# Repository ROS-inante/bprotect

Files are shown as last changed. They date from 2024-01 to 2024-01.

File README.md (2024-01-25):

# BProtect

This repository contains the design files and firmware for the BProtect battery management board.

## Overview
The battery management system consists of a LTC4281 Hot-Swap controller handling the power path control as well as a Espressif ESP32 running the interfacing firmware. 

The design was created in KiCad and can be found in the [board](/board) folder.
Some notes about design considerations, component selection and sizing are contained in the schematic.

The ESP32 runs the awesome [Tasmota](https://tasmota.github.io/docs/) firmware and has a custom driver for the LTC4281 written in [Berry](https://berry-lang.github.io/). It can be found in the [app](/app) folder.

## Usage
Assemble the board as per schematics and flash Tasmota (version >=13).
Drop the Berry-script named [ltc4281.be](/app/ltc4281.be) from the [app](/app) folder into the filesystem and add it to the 'autoexec.be' as per the example.

## License
This project is licensed under the GPLv3.

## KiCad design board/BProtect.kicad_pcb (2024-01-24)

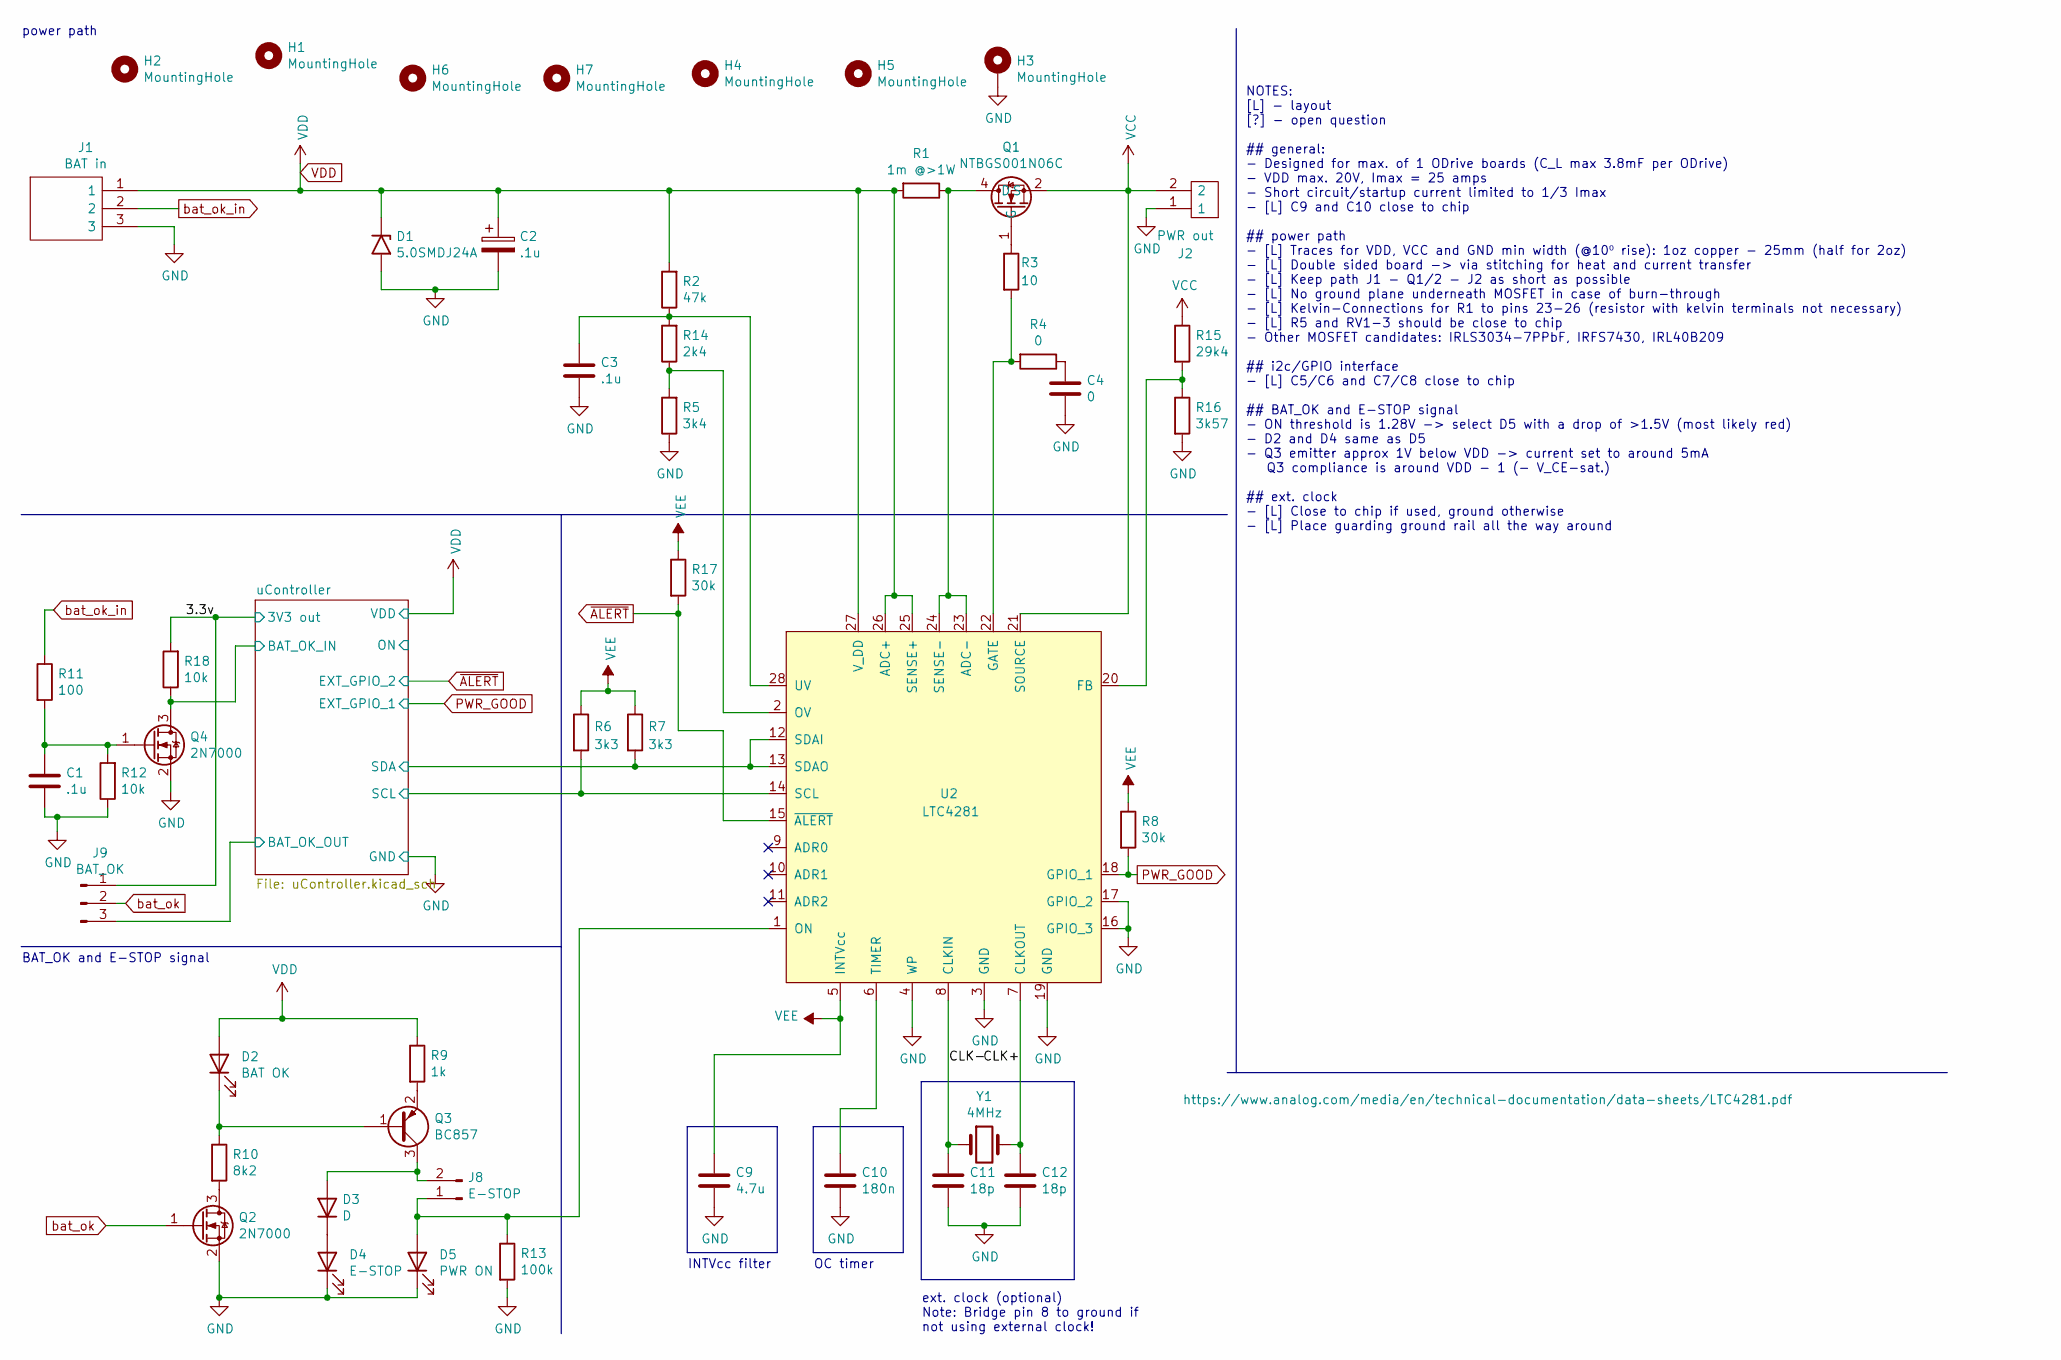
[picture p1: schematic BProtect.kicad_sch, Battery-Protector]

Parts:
C1, C3: .1u; C_1206_3216Metric_Pad1.33x1.80mm_HandSolder
C2: .1u; CP_Elec_4x5.4
C4: 0; C_1206_3216Metric_Pad1.33x1.80mm_HandSolder
C9: 4.7u; C_1206_3216Metric_Pad1.33x1.80mm_HandSolder
C10: 180n; C_1206_3216Metric_Pad1.33x1.80mm_HandSolder
C11, C12: 18p; C_0805_2012Metric_Pad1.18x1.45mm_HandSolder
D1: 5.0SMDJ24A; D_SMC_Handsoldering
D2: BAT OK; LED_1206_3216Metric_Pad1.42x1.75mm_HandSolder
D3: D; D_1206_3216Metric_Pad1.42x1.75mm_HandSolder
D4: E-STOP; LED_1206_3216Metric_Pad1.42x1.75mm_HandSolder
D5: PWR ON; LED_1206_3216Metric_Pad1.42x1.75mm_HandSolder
H1, H2, H3, H4, H5, H6, H7: MountingHole; MountingHole_3.2mm_M3_DIN965_Pad_TopBottom
J1: BAT in; 1017522
J2: PWR out; 1017521
J8: E-STOP; conn_SMD_1x03_P2.54mm_Horizontal
J9: BAT_OK; PinHeader_1x03_P2.54mm_Vertical_SMD_Pin1Left
Q1: NTBGS001N06C; TO-263-7_TabPin4
Q2, Q4: 2N7000; TSOT-23
Q3: BC857; TSOT-23
R1: 1m @>1W; R_Shunt_Vishay_WSR2_WSR3_KelvinConnection
R2: 47k; R_1206_3216Metric_Pad1.30x1.75mm_HandSolder
R3: 10; R_1206_3216Metric_Pad1.30x1.75mm_HandSolder
R4: 0; R_1206_3216Metric_Pad1.30x1.75mm_HandSolder
R5: 3k4; R_1206_3216Metric_Pad1.30x1.75mm_HandSolder
R6, R7: 3k3; R_1206_3216Metric_Pad1.30x1.75mm_HandSolder
R8, R17: 30k; R_1206_3216Metric_Pad1.30x1.75mm_HandSolder
R9: 1k; R_1206_3216Metric_Pad1.30x1.75mm_HandSolder
R10: 8k2; R_1206_3216Metric_Pad1.30x1.75mm_HandSolder
R11: 100; R_1206_3216Metric_Pad1.30x1.75mm_HandSolder
R12, R18: 10k; R_1206_3216Metric_Pad1.30x1.75mm_HandSolder
R13: 100k; R_1206_3216Metric_Pad1.30x1.75mm_HandSolder
R14: 2k4; R_1206_3216Metric_Pad1.30x1.75mm_HandSolder
R15: 29k4; R_1206_3216Metric_Pad1.30x1.75mm_HandSolder
R16: 3k57; R_1206_3216Metric_Pad1.30x1.75mm_HandSolder
U2: LTC4281; QFN-28-1EP_4x5mm_P0.5mm_EP2.65x3.65mm
Y1: 4MHz; Crystal_SMD_HC49-SD

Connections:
+3V3: J9.1, R18.2; also elsewhere on the board
/CLK+: C12.1, U2.7 (CLKOUT), Y1.2
/CLK-: C11.1, U2.8 (CLKIN), Y1.1
/uController/BAT_OK_IN: Q4.3 (D), R18.1; also elsewhere on the board
/uController/BAT_OK_OUT: J9.3; also elsewhere on the board
/uController/SCL: R6.2, U2.14 (SCL); also elsewhere on the board
/uController/SDA: R7.2, U2.12 (SDAI), U2.13 (SDAO); also elsewhere on the board
GND: C1.2, C2.2, C3.2, C4.2, C9.2, C10.2, C11.2, C12.2, D1.2 (A2), D4.1 (K), D5.1 (K), H3.1, J1.3, J2.1, Q2.2 (S), Q4.2 (S), R5.1, R12.1, R13.2, R16.2, U2.3 (GND), U2.4 (WP), U2.16 (GPIO_3), U2.17 (GPIO_2), U2.19 (GND), U2.29; also elsewhere on the board
unnamed: C1.1, Q4.1 (G), R11.2, R12.2
unnamed: C3.1, R2.1, R14.2, U2.28 (UV)
unnamed: C4.1, R4.1
unnamed: C10.1, U2.6 (TIMER)
unnamed: D2.1 (K), Q3.1 (B), R10.1
unnamed: D3.1 (K), D4.2 (A)
unnamed: D3.2 (A), J8.2, Q3.3 (C)
unnamed: D5.2 (A), J8.1, R13.1, U2.1 (ON)
unnamed: Q1.1 (G), R3.1
unnamed: Q2.3 (D), R10.2
unnamed: Q3.2 (E), R9.2
unnamed: R3.2, R4.2, U2.22 (GATE)
unnamed: R5.2, R14.1, U2.2 (OV)
unnamed: R15.2, R16.1, U2.20 (FB)
PWR_GOOD: R8.2, U2.18 (GPIO_1); also elsewhere on the board
VDD: C2.1, D1.1 (A1), D2.2 (A), J1.1, R1.2, R2.2, R9.1, U2.25 (SENSE+), U2.26 (ADC+), U2.27 (V_DD); also elsewhere on the board
VEE: C9.1, R6.1, R7.1, R8.1, R17.1, U2.5 (INTVcc)
bat_ok: J9.2, Q2.1 (G)
bat_ok_in: J1.2, R11.1
~ALERT: R17.2, U2.15 (~ALERT); also elsewhere on the board

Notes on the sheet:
INTVcc filter
NOTES: [L] - layout [?] - open question ## general: - Designed for max. of 1 ODrive boards (C_L max 3.8mF per ODrive) - VDD max. 20V, Imax = 25 amps - Short circuit/startup current limited to 1/3 Imax - [L] C9 and C10 close to chip ## power path - [L] Traces for VDD, VCC and GND min width (@10⁰ ris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
power path
BAT_OK and E-STOP signal
OC timer
ext. clock (optional) Note: Bridge pin 8 to ground if not using external clock!

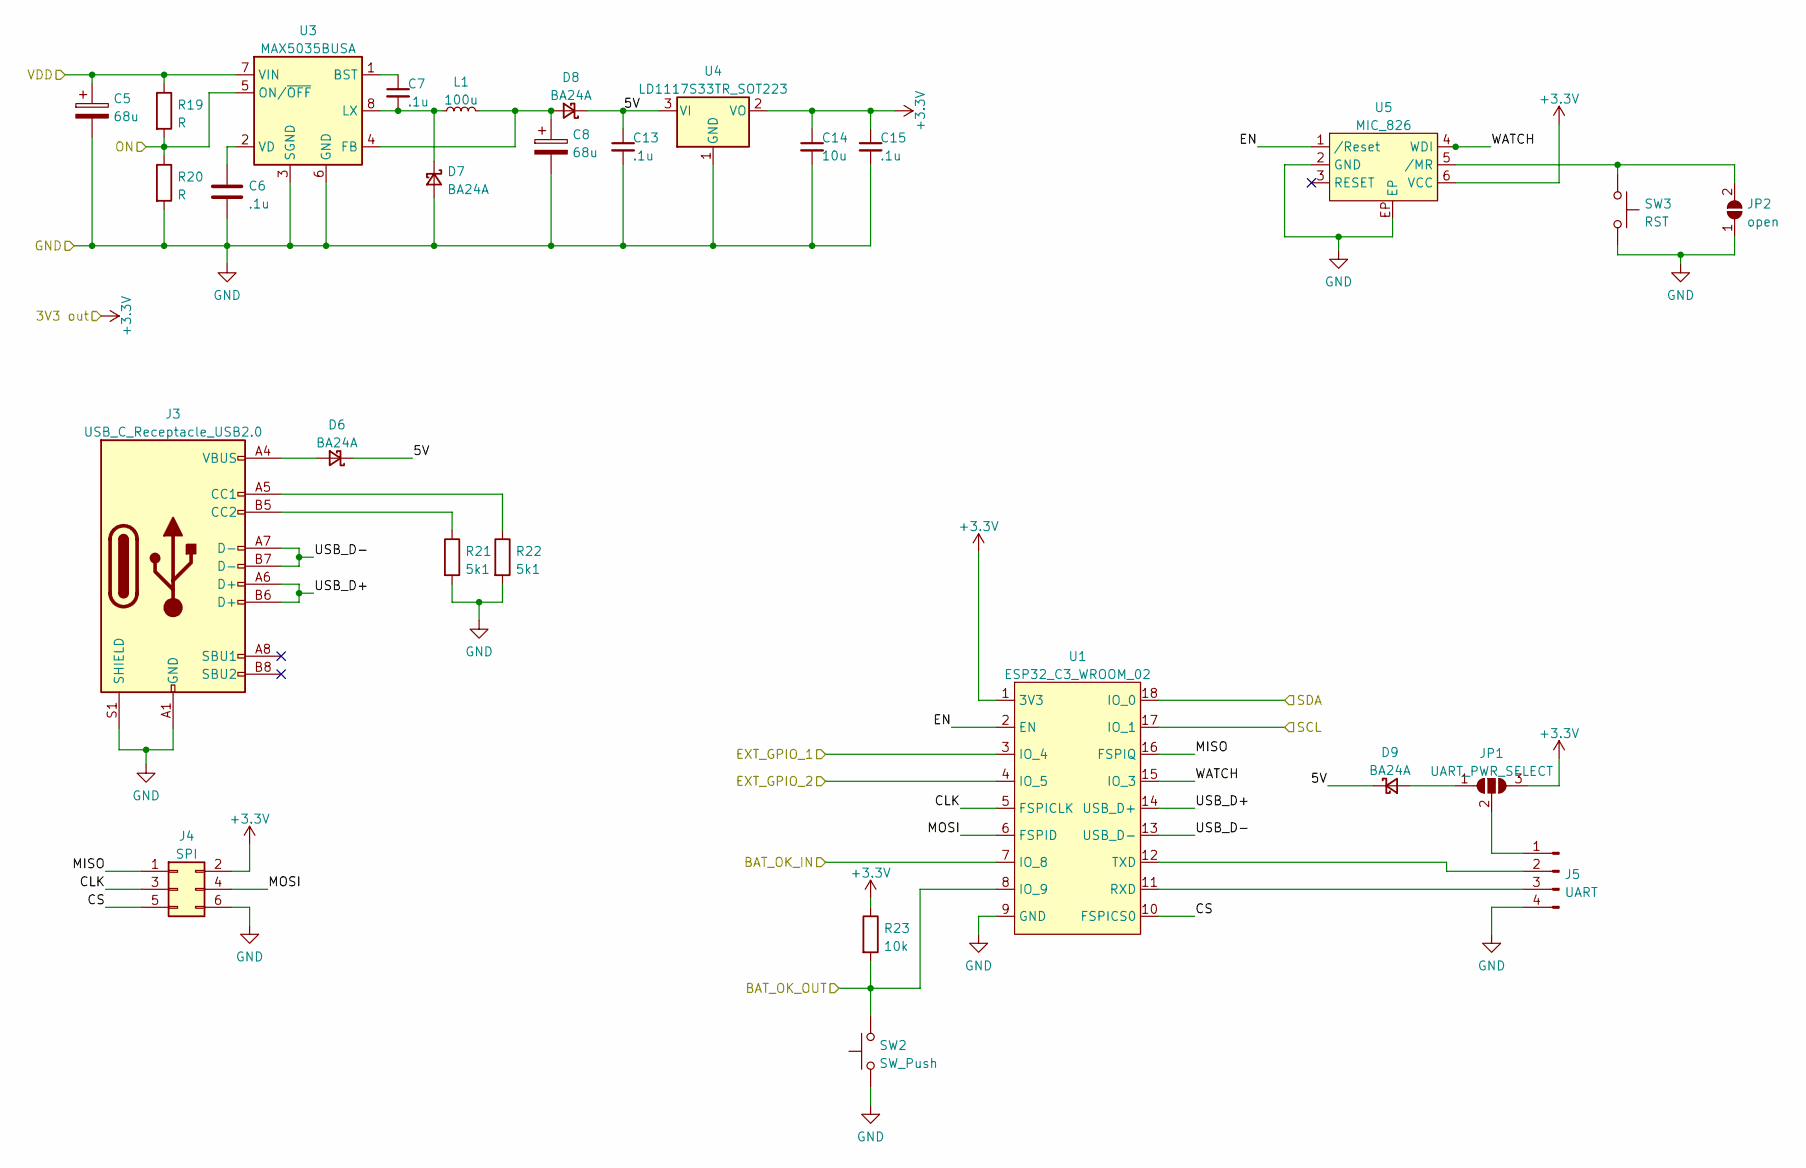
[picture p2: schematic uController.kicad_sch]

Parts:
C5, C8: 68u; CP_Elec_4x5.4
C6, C7, C13, C15: .1u; C_1206_3216Metric_Pad1.33x1.80mm_HandSolder
C14: 10u; C_1206_3216Metric_Pad1.33x1.80mm_HandSolder
D6, D7, D8, D9: BA24A; D_SMA
J3: USB_C_Receptacle_USB2.0; USB_C_Receptacle_JAE_DX07S016JA1R1500
J4: SPI; PinSocket_2x03_P2.54mm_Vertical
J5: UART; PinSocket_1x04_P2.54mm_Vertical
JP1: UART_PWR_SELECT; SolderJumper-3_P1.3mm_Open_RoundedPad1.0x1.5mm_NumberLabels
JP2: open; SolderJumper-2_P1.3mm_Open_RoundedPad1.0x1.5mm
L1: 100u; L_12x12mm_H8mm
R19, R20: R; R_1206_3216Metric_Pad1.30x1.75mm_HandSolder
R21, R22: 5k1; R_1206_3216Metric_Pad1.30x1.75mm_HandSolder
R23: 10k; R_1206_3216Metric_Pad1.30x1.75mm_HandSolder
SW2: SW_Push; SW_Push_1P1T_NO_CK_KSC2xxJ
SW3: RST; SW_Push_1P1T_NO_CK_KSC2xxJ
U1: ESP32_C3_WROOM_02; ESP-13-WROOM-02
U3: MAX5035BUSA; SOIC-8_3.9x4.9mm_P1.27mm
U4: LD1117S33TR_SOT223; SOT-223-3_TabPin2
U5: MIC_826; TDFN-6-1EP_1.6x1.6mm_P0.5mm_EP0.5x1.4mm

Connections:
+3V3: C14.1, C15.1, J4.2, JP1.3 (B), R23.1, U1.1 (3V3), U4.2 (VO), U5.6 (VCC); also elsewhere on the board
/uController/5V: C13.1, D6.1 (K), D8.1 (K), D9.1 (K), U4.3 (VI)
/uController/BAT_OK_IN: U1.7 (IO_8); also elsewhere on the board
/uController/BAT_OK_OUT: R23.2, SW2.2, U1.8 (IO_9); also elsewhere on the board
/uController/CLK: J4.3, U1.5 (FSPICLK)
/uController/CS: J4.5, U1.10 (FSPICS0)
/uController/EN: U1.2 (EN), U5.1 (/Reset)
/uController/MISO: J4.1, U1.16 (FSPIQ)
/uController/MOSI: J4.4, U1.6 (FSPID)
/uController/ON: R19.2, R20.1, U3.5 (ON/~OFF)
/uController/SCL: U1.17 (IO_1); also elsewhere on the board
/uController/SDA: U1.18 (IO_0); also elsewhere on the board
/uController/USB_D+: J3.A6 (D+), J3.B6 (D+), U1.14 (USB_D+)
/uController/USB_D-: J3.A7 (D-), J3.B7 (D-), U1.13 (USB_D-)
/uController/WATCH: U1.15 (IO_3), U5.4 (WDI)
GND: C5.2, C6.2, C8.2, C13.2, C14.2, C15.2, D7.2 (A), J3.A1 (GND), J3.A12 (GND), J3.B1 (GND), J3.B12 (GND), J3.S1 (SHIELD), J4.6, J5.4, JP2.1 (A), R20.2, R21.2, R22.2, SW2.1, SW3.2, U1.9 (GND), U1.PAD, U3.3 (SGND), U3.6 (GND), U4.1 (GND), U5.2 (GND), U5.EP; also elsewhere on the board
unnamed: C6.1, U3.2 (VD)
unnamed: C7.1, U3.1 (BST)
unnamed: C7.2, D7.1 (K), L1.1, U3.8 (LX)
unnamed: C8.1, D8.2 (A), L1.2, U3.4 (FB)
unnamed: D6.2 (A), J3.A4 (VBUS), J3.A9 (VBUS), J3.B4 (VBUS), J3.B9 (VBUS)
unnamed: D9.2 (A), JP1.1 (A)
unnamed: J3.A5 (CC1), R22.1
unnamed: J3.B5 (CC2), R21.1
unnamed: J5.1, JP1.2 (C)
unnamed: J5.2, U1.12 (TXD)
unnamed: J5.3, U1.11 (RXD)
unnamed: JP2.2 (B), SW3.1, U5.5 (/MR)
PWR_GOOD: U1.3 (IO_4); also elsewhere on the board
VDD: C5.1, R19.1, U3.7 (VIN); also elsewhere on the board
~ALERT: U1.4 (IO_5); also elsewhere on the board

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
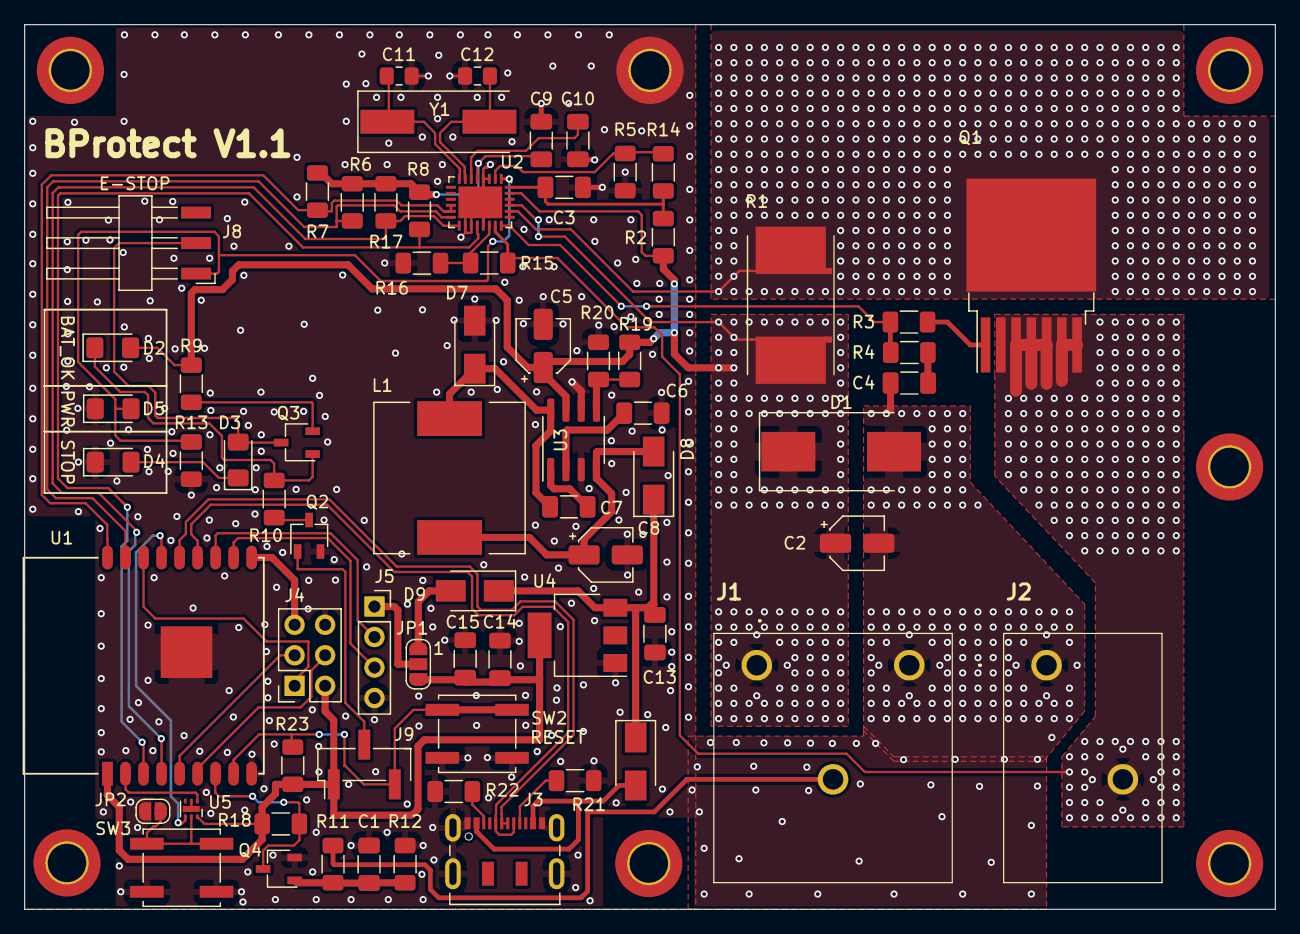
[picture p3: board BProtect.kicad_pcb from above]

Board: 2 copper layers, 104.1 x 73.7 mm, 76 parts (0 on the bottom side), 52 nets.

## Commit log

2024-01-24 Added board design files.
    [BProtect.kicad_pcb, BProtect.kicad_sch, BProtect.sch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]
2024-01-25 Added berry driver
